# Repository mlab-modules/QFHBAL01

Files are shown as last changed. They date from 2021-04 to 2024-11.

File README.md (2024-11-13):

# QFHBAL01 - Antenna Interface and Balun

The **QFHBAL01** module is an [antenna interface and balun](https://en.wikipedia.org/wiki/Balun) designed for QFH (Quadrifilar Helix) antennas, supporting right-hand (RHCP) and left-hand circular polarizations (LHCP). This module enables efficient impedance matching and balanced transmission in QFH antenna configurations.

QFH antenna balun

## Key Features

- **Polarization**: RHCP and LHCP
- **Frequency Range**: 4.5 - 3000 MHz
- **Insertion Loss**: 2 dB typical
- **Amplitude Balance**: ±1 dB
- **Phase Balance**: ±20°
- **Power Rating**: 250 mW max RF, 30 mA max DC
- **Operating Temperature**: -55 °C to +85 °C
- **Dimensions**: Diameter 32 mm, Height 20 mm
- **Weight**: 10 g

## Transformer Mounting Options

The **ETC1-1-13** transformer on the QFHBAL01 module can be soldered onto the PCB in two configurations:

1. **Galvanic Isolation**: Isolates the antenna from the RF line, enhancing protection for the receiver input but potentially increasing insertion loss slightly.
2. **Direct Galvanic Connection**: Connects the antenna directly to the RF line without isolation, minimizing insertion loss but offering less protection for the receiver input.

These configurations allow customization based on application requirements for input protection and insertion loss.

### Balun Polarization and Connection

Balun connection

| Helices | Feedpoint | Radiation | Polarization |
|---|---|---|---|
| Left-hand | Standard | Upward | RHCP |
| Right-hand  | Anti-standard  | Upward | LHCP |
| Left-hand | Anti-standard  | Downward  | RHCP |
| Right-hand  | Standard | Downward  | LHCP |

*Source: [QHA Simulation](https://uuki.kapsi.fi/qha_simul.html)*

## Schematic and Mechanical Drawing

- [Schematic (PDF)](/doc/gen/QFHBAL01-schematic.pdf)
- [Mechanical Drawing (PDF)](/doc/src/img/dimensions.png)

### ETC1-1-13 Transformer Specifications

The **ETC1-1-13** transformer offers a 1:1 impedance ratio suitable for balanced RF transmission:

- **Frequency Range**: 4.5 - 3000 MHz
- **Insertion Loss**: 0.32 dB typical, max 3.5 dB at high frequencies
- **Amplitude Balance**: ±1 dB
- **Phase Balance**: ±20°
- **Power Rating**: 250 mW max
- **Operating Temperature**: -55°C to +85°C

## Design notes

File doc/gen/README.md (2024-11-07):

# PCB

Board size: 32.0x32.0 mm (1.26x1.26 inches)

- This is the size of the rectangle that contains the board
- Thickness: 1.6 mm (63 mils)
- Material: FR4
- Finish: None
- Layers: 2
- Copper thickness: 35 µm

Solder mask: TOP / BOTTOM

- Color: Green

Silk screen: TOP / BOTTOM

- Color: White

Stackup:

| Name | Type | Color | Thickness [µm]| Material | Er | Loss tan |
|---|---|---|---|---|---|---|
| F.SilkS | Top Silk Screen | | | | | |
| F.Paste | Top Solder Paste | | | | | |
| F.Mask | Top Solder Mask | Green | 10 | | | |
| F.Cu | copper | | 35 | | | |
| dielectric 1 | core | | 1510 | FR4 | 4.5 | 0.020 |
| B.Cu | copper | | 35 | | | |
| B.Mask | Bottom Solder Mask | Green | 10 | | | |
| B.Paste | Bottom Solder Paste  | | | | | |
| B.SilkS | Bottom Silk Screen | | | | | |

# Important sizes

Clearance: 0.2 mm (8 mils)

Track width: 0.5 mm (20 mils)

- By design rules: 0.2 mm (8 mils)

Drill: 0.5 mm (20 mils)

- Vias: 0.5 mm (20 mils) [Design: 0.4 mm (16 mils)]
- Pads: 1.6 mm (63 mils)
- The above values are real drill sizes, they add 0.1 mm (4 mils) to plated holes (PTH)

Via: 0.8/0.4 mm (31/16 mils)

- By design rules: 0.4/0.3 mm (16/12 mils)
- Micro via: yes [0.2/0.1 mm (8/4 mils)]
- Buried/blind via: yes
- Total: 54 (thru: 54 buried/blind: 0 micro: 0)

Outer Annular Ring: 0.15 mm (6 mils)

- By design rules: 0.23 mm (9 mils)

Eurocircuits class: 4B
- Using min drill 0.5 mm for an OAR of 0.15 mm

# General stats

Components count: (SMD/THT)

- Top: 1/1 (SMD + THT)
- Bottom: 1/0 (SMD)

Defined tracks:

- 0.5 mm (20 mils)
- 1.0 mm (39 mils)
- 2.1 mm (83 mils)

Used tracks:

- 0.5 mm (20 mils) (2) defined: yes
- 0.86 mm (34 mils) (6) defined: no
- 1.0 mm (39 mils) (4) defined: yes
- 2.1 mm (83 mils) (13) defined: yes

Defined vias:

Used vias:

- 0.8/0.4 mm (31/16 mils) (Count: 54, Aspect: 2.0 A) defined: no

Holes (excluding vias):

- 1.5 mm (59 mils) (1)
- 1.7 mm (67 mils) (4)
- 2.2 mm (87 mils) (4)
- 3.2 mm (126 mils) (3)

Oval holes:

Drill tools (including vias and computing adjusts and rounding):

- 0.5 mm (20 mils) (54)
- 1.6 mm (63 mils) (1)
- 1.8 mm (71 mils) (4)
- 2.3 mm (91 mils) (4)
- 3.2 mm (126 mils) (3)

Solder paste stats:

Using a paste with 87.75 % alloy, that has an specific gravity for the alloy of 7.4 g/cm³
and 1.0 g/cm³ for the flux. This paste has an specific gravity of  4.15 g/cm³.

The stencil thickness is  0.12 mm.

| Side | Pads with paste | Area [mm²] | Paste [g] |
|---|---|---|---|
| Top | 5 | 5.32 | 0.03 |
| Bottom | 5 | 5.32 | 0.03 |
| Total  | 10 | 10.64 | 0.05 |

Note: this is just an approximation to the theoretical value. Margins of the solder mask and waste aren't computed.

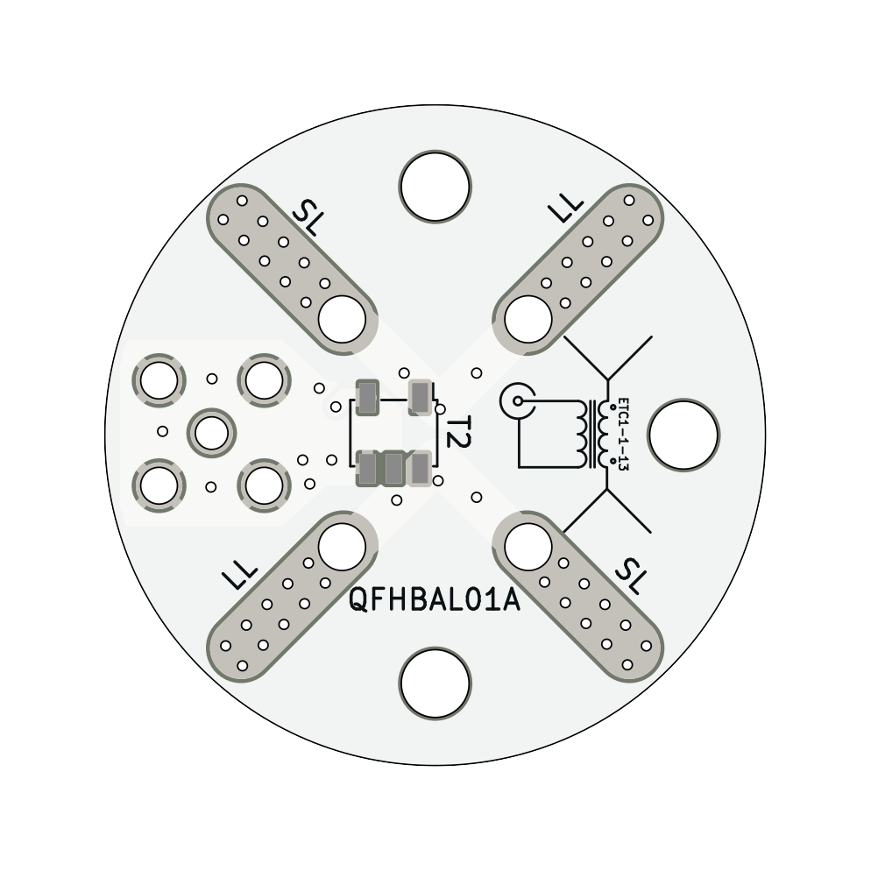
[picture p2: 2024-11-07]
doc/gen/img/QFHBAL01-bottom.png

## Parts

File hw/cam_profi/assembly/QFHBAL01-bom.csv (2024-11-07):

Component | Description | Part | References | Value | Footprint | Quantity Per PCB | Datasheet
1 | coaxial connector (BNC, SMA, SMB, SMC, Cinch/RCA, ...) | Conn_Coaxial | J1 | Conn_Coaxial SMA or MCX | SMA_Amphenol_901-144_Vertical | 1 | ~
2 |  | ETC1-1-13-riske-symbols | T1T2 | ETC1-1-13 | Transformer_MACOM_SM-22 | 2 | https://www.minicircuits.com/pdfs/TC1-1-13MX+.pdf

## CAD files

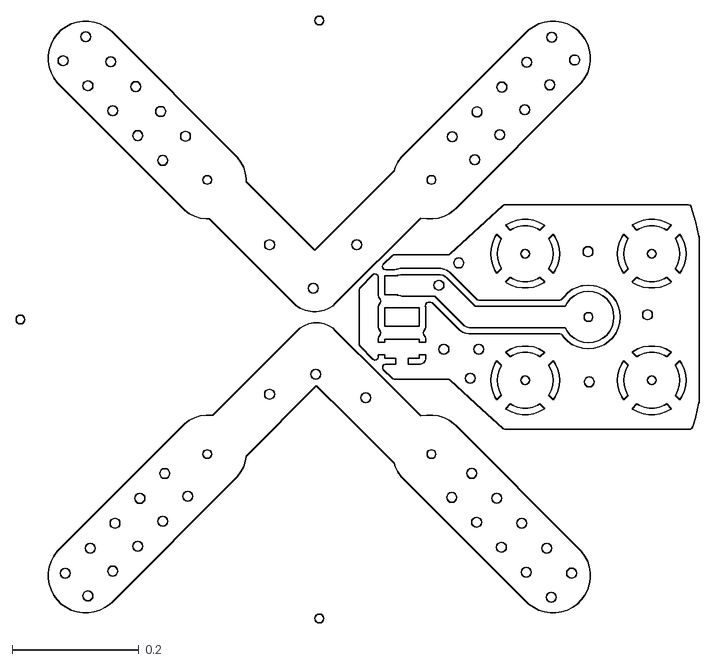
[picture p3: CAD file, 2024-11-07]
doc/gen/dxf/QFHBAL01-F_Cu.dxf
1.08 x 0.959

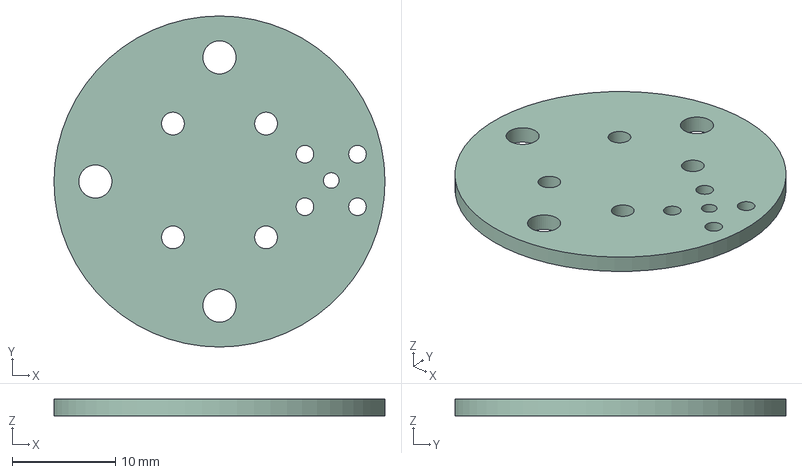
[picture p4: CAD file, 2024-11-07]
doc/gen/QFHBAL01.step
32.0 x 32.0 x 1.60 mm

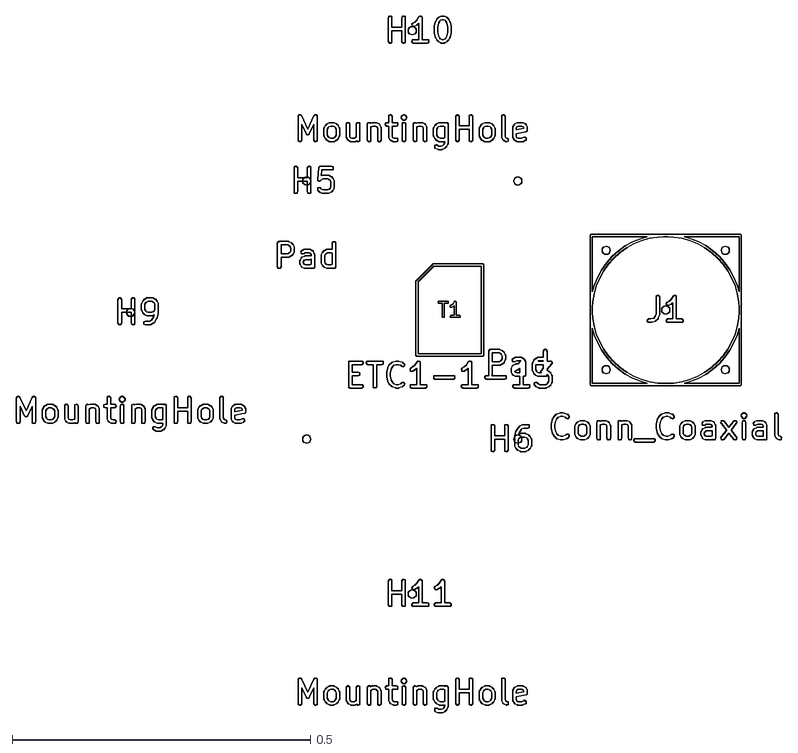
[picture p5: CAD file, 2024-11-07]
doc/gen/dxf/QFHBAL01-F_Fab.dxf
1.28 x 1.17

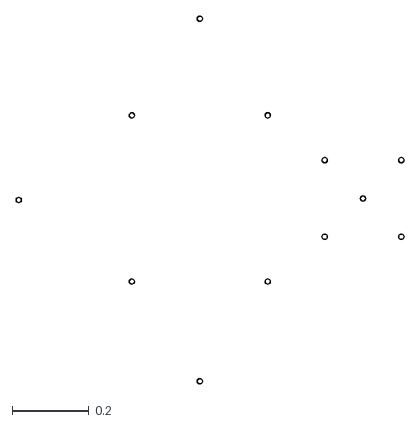
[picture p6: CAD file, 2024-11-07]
doc/gen/dxf/QFHBAL01-User_Eco2.dxf
1.01 x 0.959

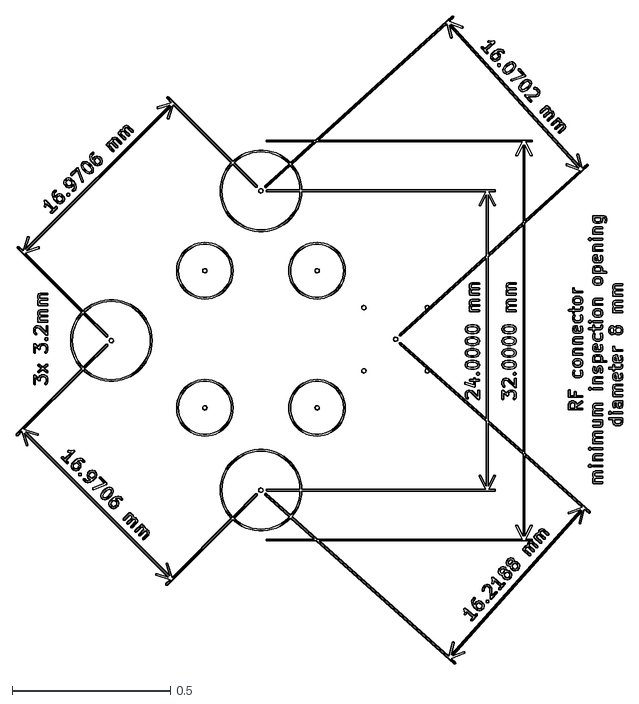
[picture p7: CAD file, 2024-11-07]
doc/gen/dxf/QFHBAL01-User_Comments.dxf
1.92 x 2.05

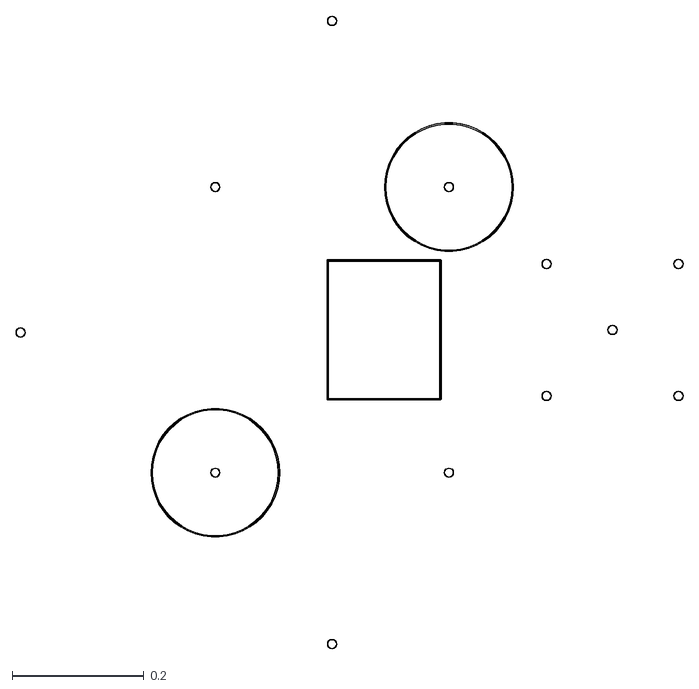
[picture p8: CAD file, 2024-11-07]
doc/gen/dxf/QFHBAL01-B_Courtyard.dxf
1.01 x 0.959

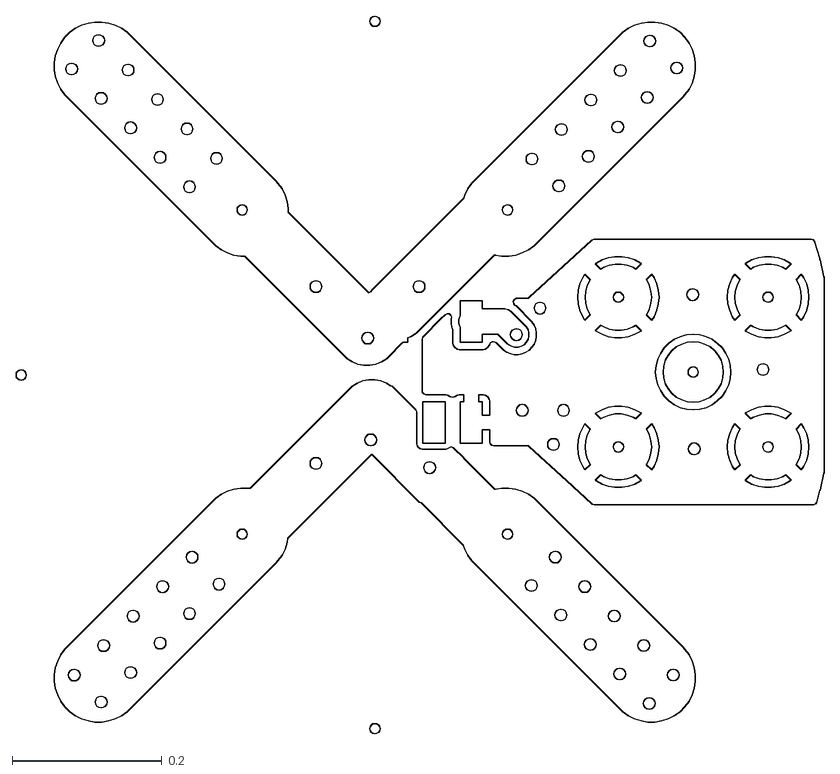
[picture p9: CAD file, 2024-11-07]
doc/gen/dxf/QFHBAL01-B_Cu.dxf
1.08 x 0.959

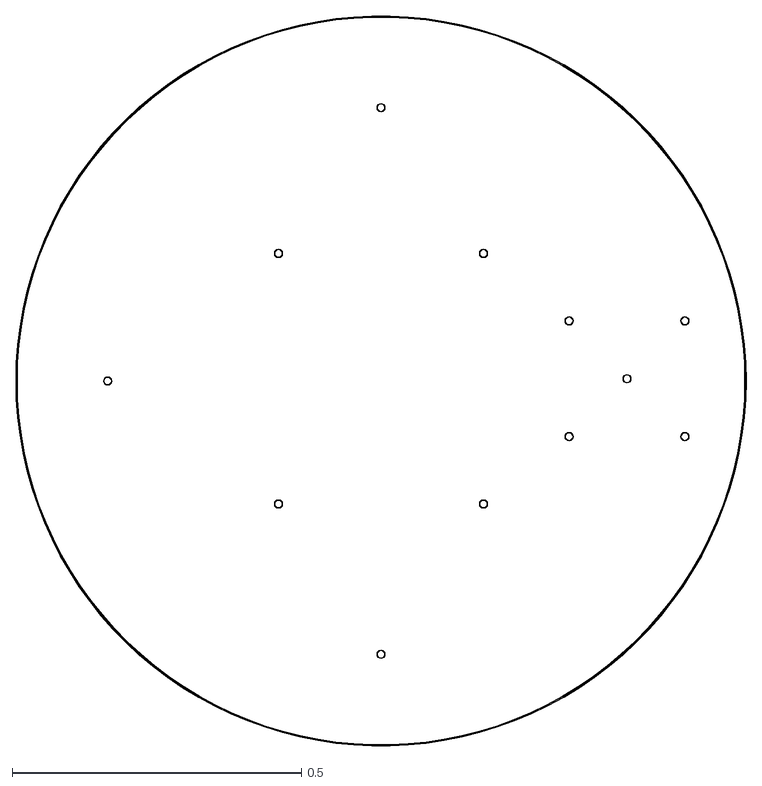
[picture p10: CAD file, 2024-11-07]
doc/gen/dxf/QFHBAL01-Edge_Cuts.dxf
1.26 x 1.26

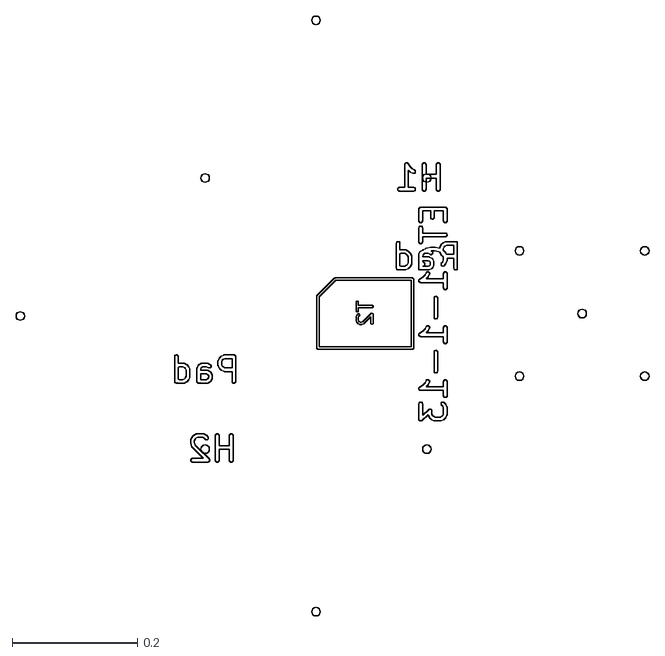
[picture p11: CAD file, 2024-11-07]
doc/gen/dxf/QFHBAL01-B_Fab.dxf
1.01 x 0.959

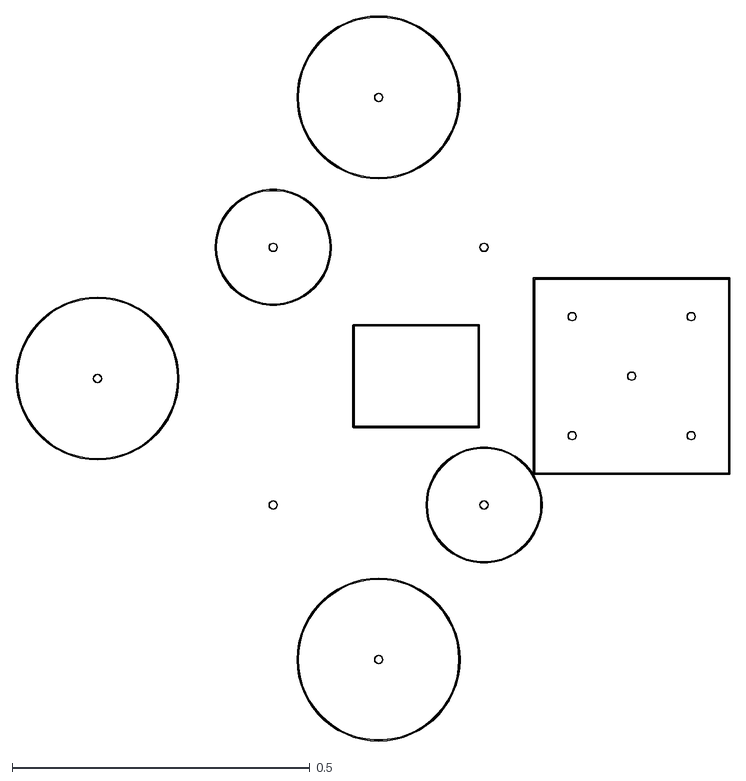
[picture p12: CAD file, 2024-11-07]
doc/gen/dxf/QFHBAL01-F_Courtyard.dxf
1.20 x 1.22

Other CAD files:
doc/gen/dxf/QFHBAL01-B_Adhesive.dxf
doc/gen/dxf/QFHBAL01-F_Adhesive.dxf
doc/gen/dxf/QFHBAL01-B_Mask.dxf
doc/gen/dxf/QFHBAL01-B_Paste.dxf
doc/gen/dxf/QFHBAL01-B_Silkscreen.dxf
doc/gen/dxf/QFHBAL01-F_Mask.dxf
doc/gen/dxf/QFHBAL01-F_Paste.dxf
doc/gen/dxf/QFHBAL01-F_Silkscreen.dxf

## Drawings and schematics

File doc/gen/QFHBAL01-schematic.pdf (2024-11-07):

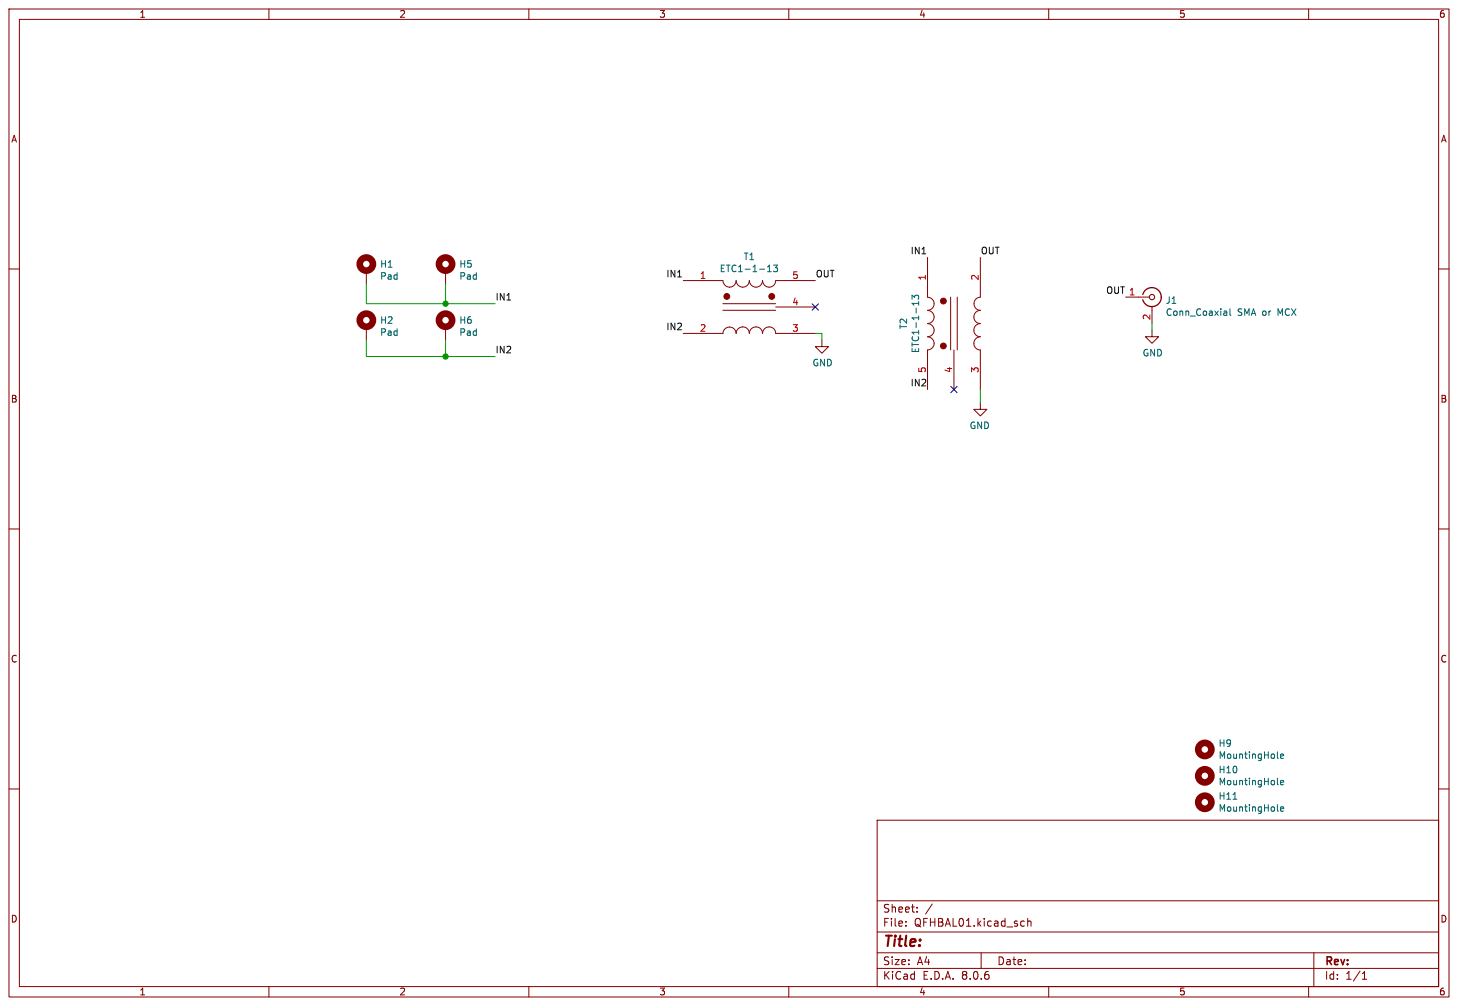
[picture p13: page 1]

Id: 1/1 Title: File: QFHBAL01.kicad_sch Sheet: /

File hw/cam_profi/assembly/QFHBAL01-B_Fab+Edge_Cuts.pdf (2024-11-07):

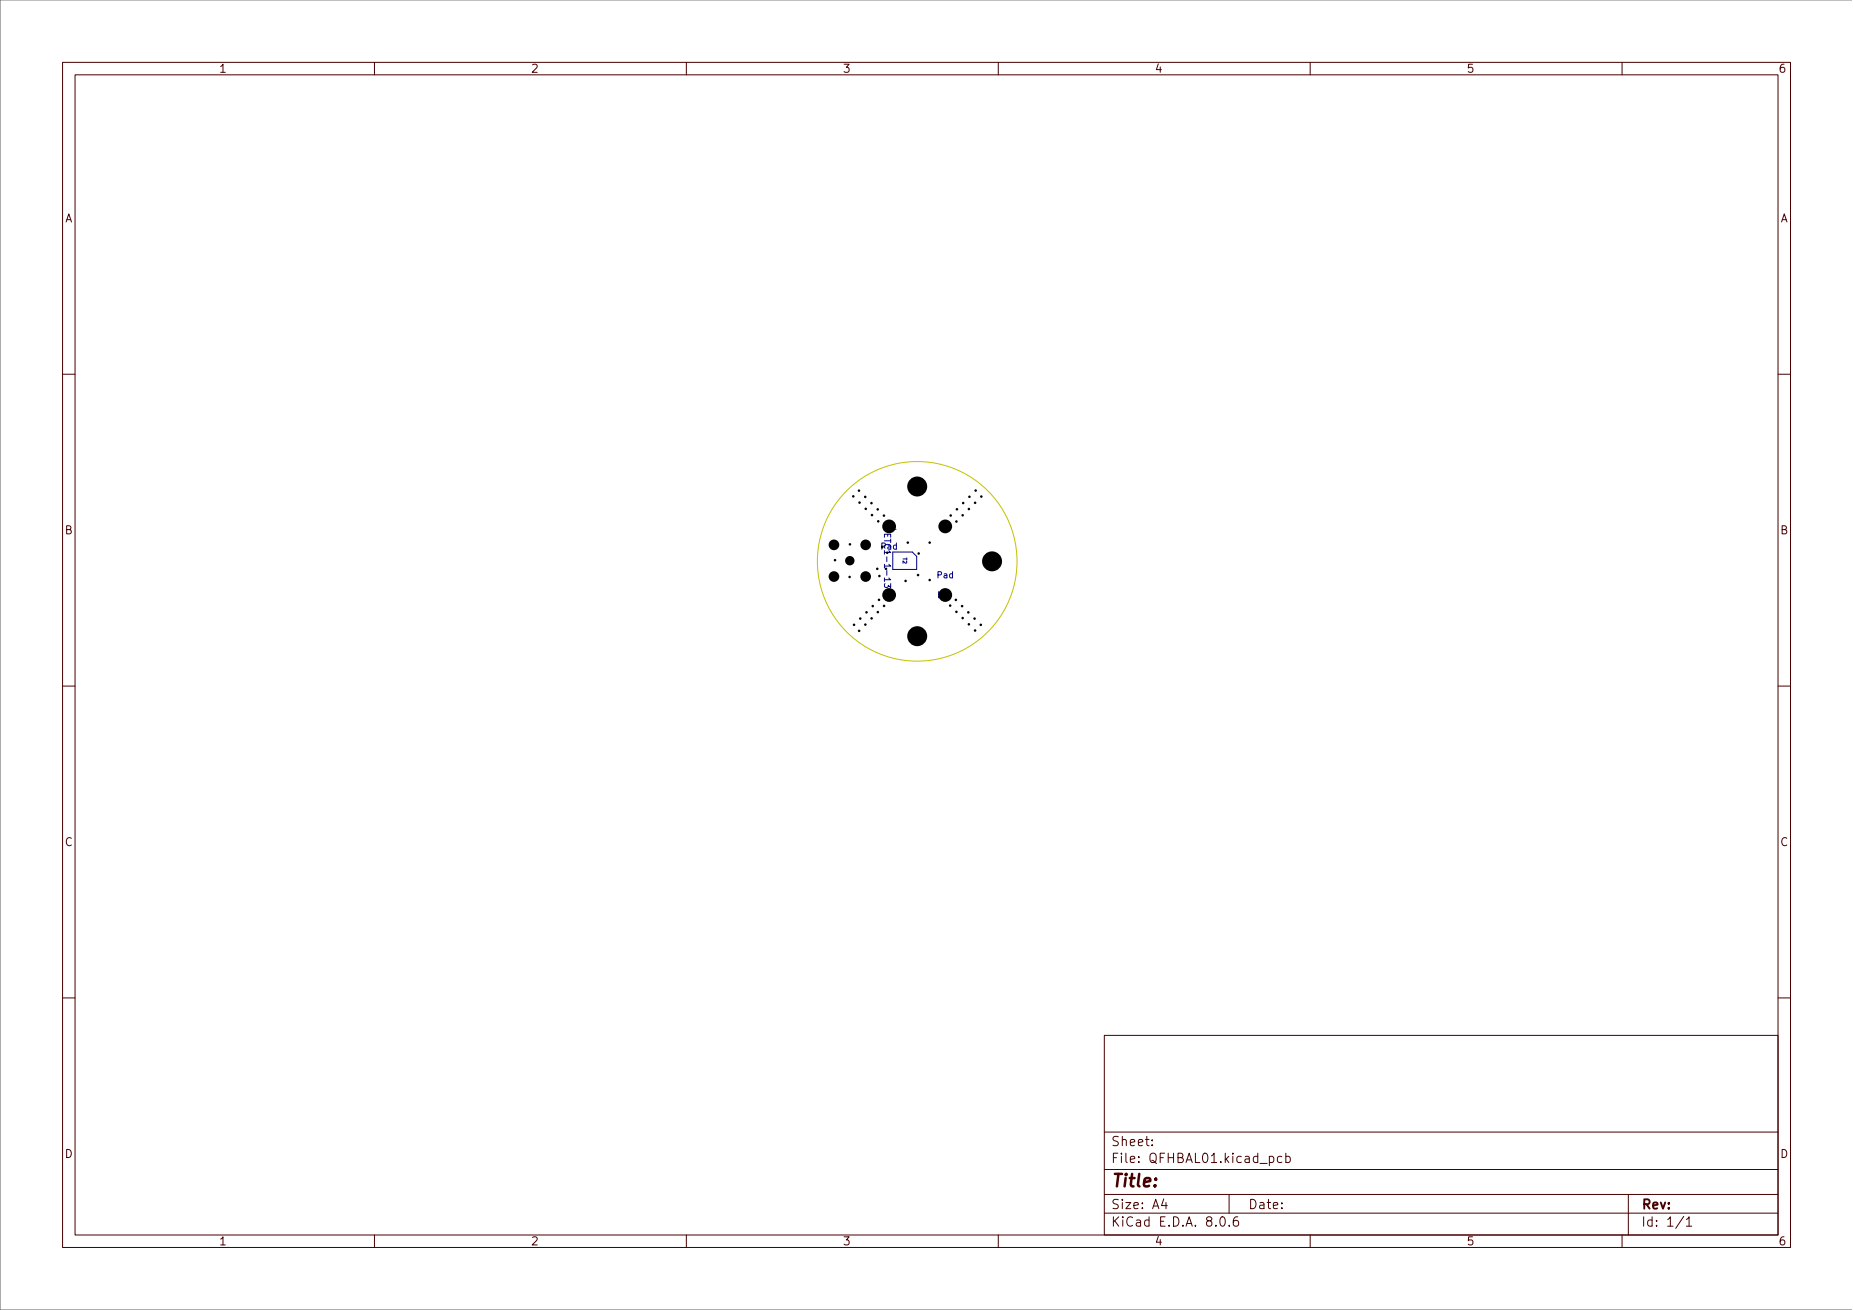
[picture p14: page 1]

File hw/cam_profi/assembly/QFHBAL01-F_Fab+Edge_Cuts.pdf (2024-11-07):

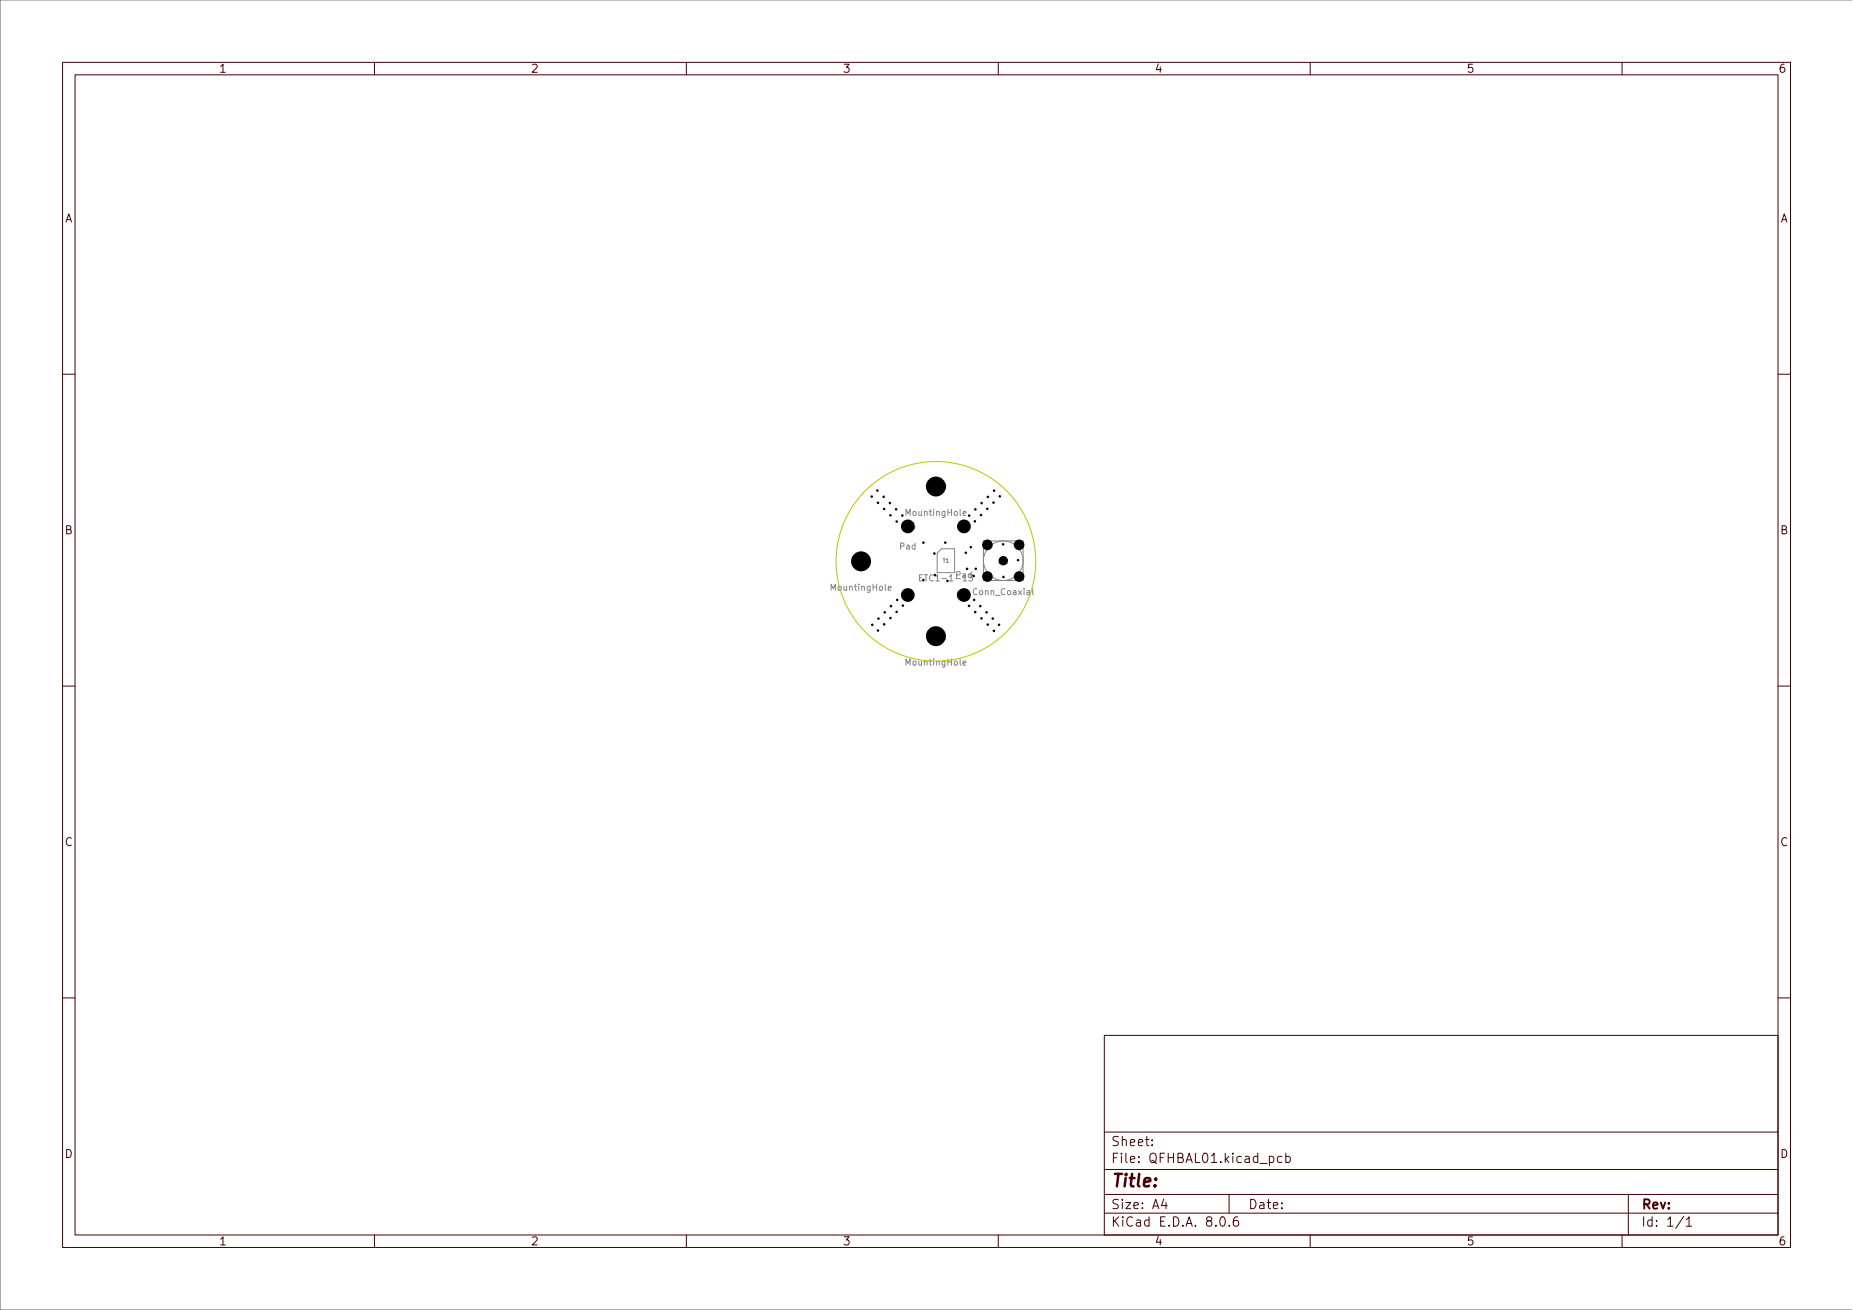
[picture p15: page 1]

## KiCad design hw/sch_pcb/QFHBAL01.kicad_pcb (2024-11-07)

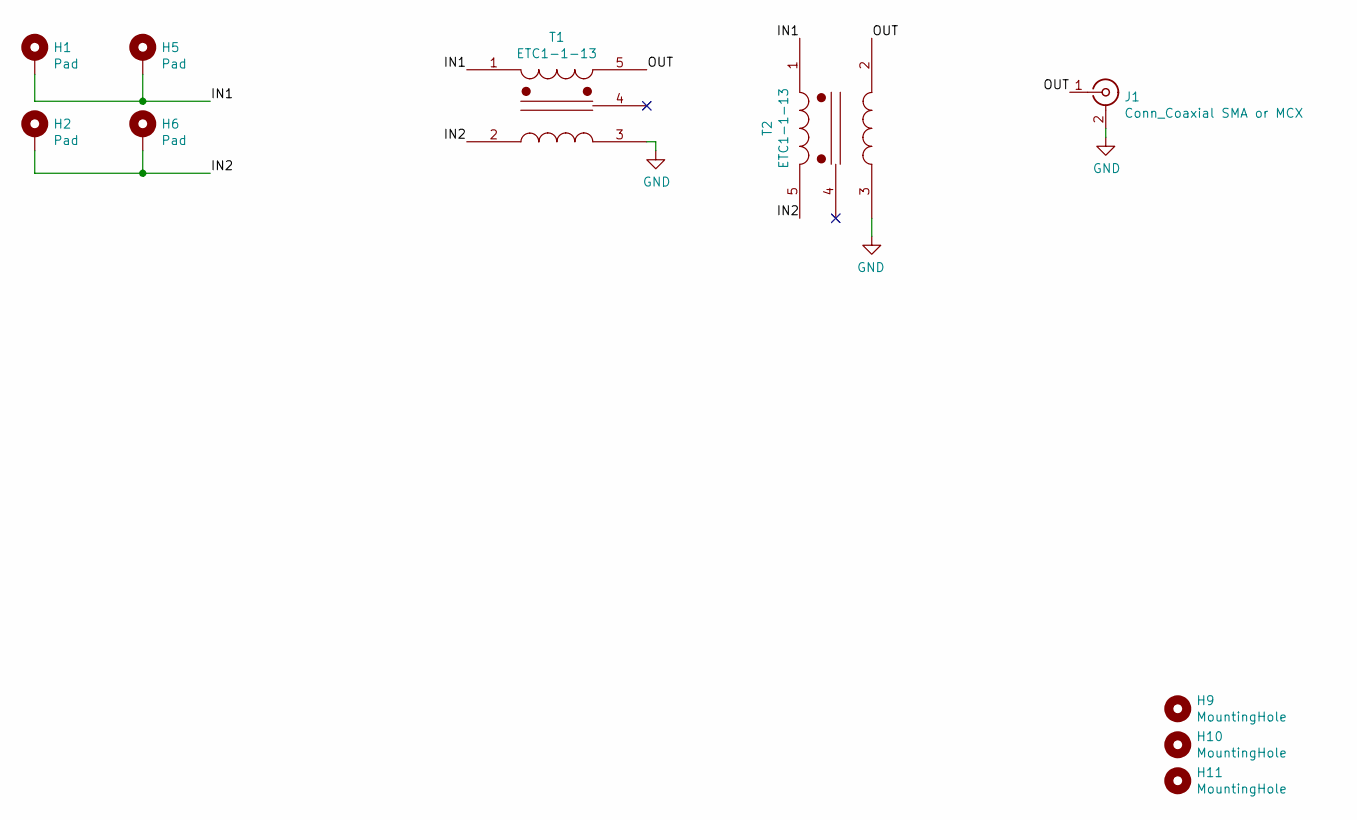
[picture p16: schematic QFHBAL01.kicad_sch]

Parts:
H1, H2, H5, H6: Pad; MountingHole_2.2mm_M2_Pad
H9, H10, H11: MountingHole; MountingHole_3.2mm_M3
J1: Conn_Coaxial SMA or MCX; SMA_Amphenol_901-144_Vertical
T1, T2: ETC1-1-13; Transformer_MACOM_SM-22

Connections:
/IN1: H1.1, H5.1, T1.1 (AA), T2.1 (AA)
/IN2: H2.1, H6.1, T1.2 (AB), T2.5 (SB)
/OUT: J1.1 (In), T1.5 (SB), T2.2 (AB)
GND: J1.2 (Ext), T1.3 (SA), T2.3 (SA)

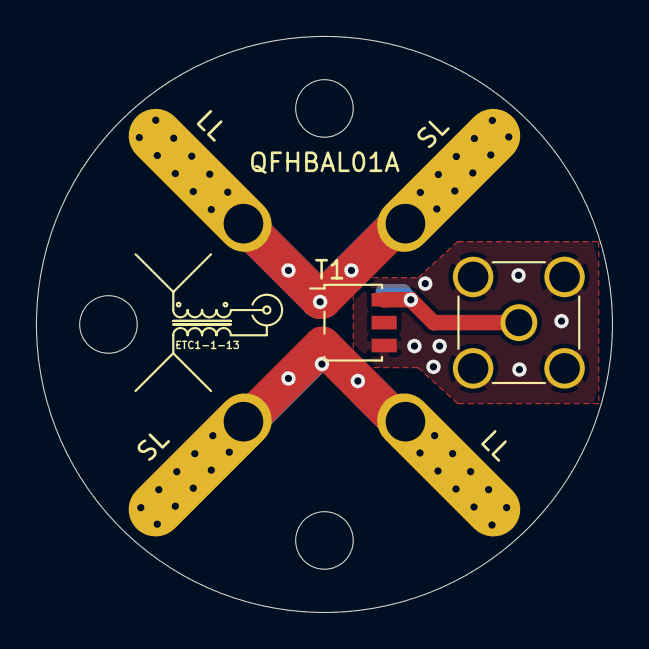
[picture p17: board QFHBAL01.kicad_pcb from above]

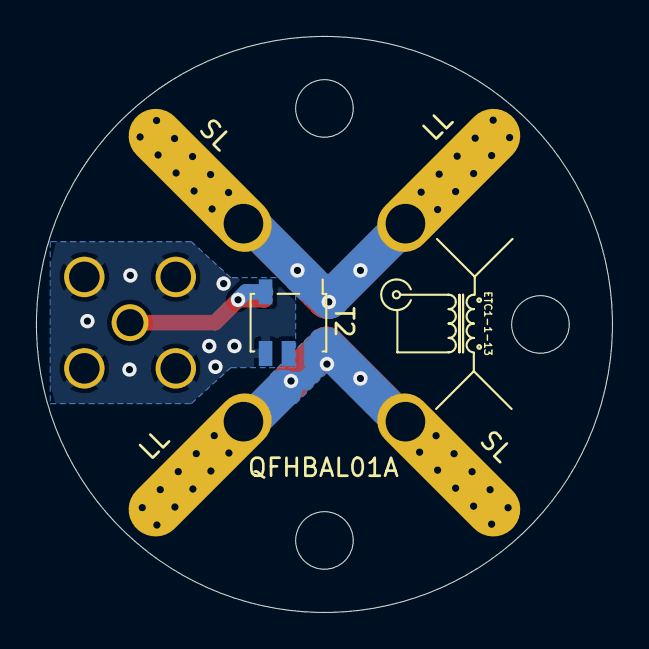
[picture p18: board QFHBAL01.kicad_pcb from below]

Board: 2 copper layers, 32.0 x 32.0 mm, 10 parts (3 on the bottom side), 4 nets.

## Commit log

2022-04-06 Update actions products
    [QFHBAL01-Edge_Cuts.dxf, QFHBAL01-F_Cu.dxf, QFHBAL01-F_Mask.dxf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]
2024-11-07 update assets, save in KiCADv8
    [QFHBAL01.kicad_pcb, QFHBAL01.kicad_sch]
